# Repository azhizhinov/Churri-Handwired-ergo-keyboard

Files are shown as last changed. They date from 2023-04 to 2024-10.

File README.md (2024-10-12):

This keyboard has been originaly designed by leafflat, this repo is just a fork of his beautiful creation. 

Here is my first custom keyboard design.If you make one, please send me a picture or at me on reddit u/leifflat.

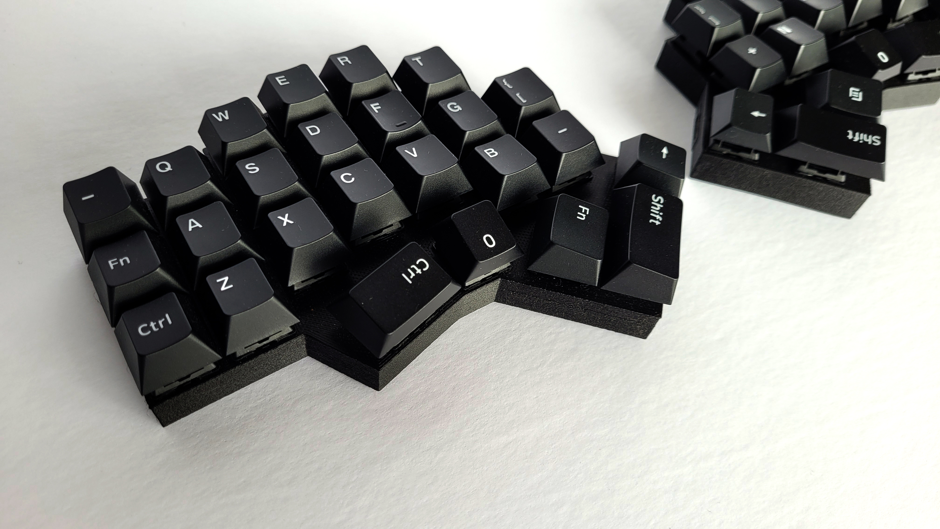
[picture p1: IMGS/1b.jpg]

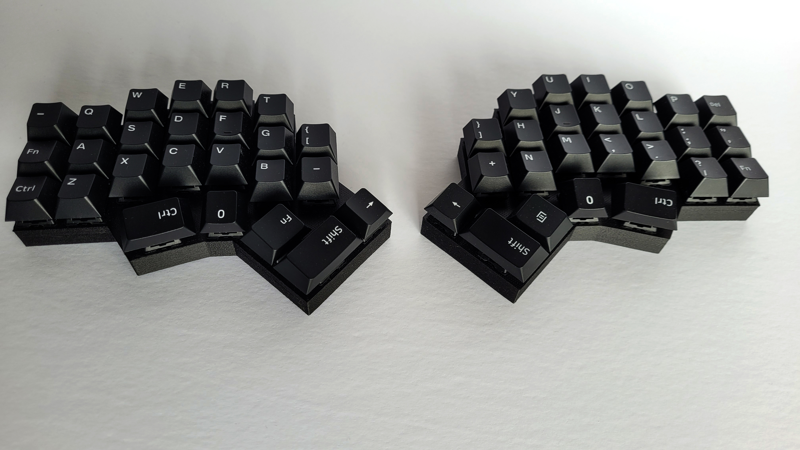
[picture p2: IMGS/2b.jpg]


The keymap is very basic and is for sure missing some things as I intended from the start to use Vial which is the hex I would suggest using, but you can compile it yourself with the provided files.
All the STL files are for one side, and just need to be mirrored for the other side.
<br>
| QTY  | Item |
| --- | --- |
| 6  | 25mm M3 head cap bolts  |
| 18 | 8mm M3 flat head bolts  |
| 12  | M3 heat press inserts (4.5 OD) |
| 12  | M3 nuts  |
| 50 | MX switches  |
| 50 | 1N4148 Diodes  |
| 2 | Pro Micros  |
| 4  | Female USB C breakout boards (see picture below for which one to get specifically)  |
| 2 | Male Micro USB ends  |
| 2  | Tact switches  |

Tenting legs:
Heat press one nut on one side of all 6 through holes to catch the 25mm bolt.<br>
I dipped the tips in Plastidip to give them a better grip on my desk mat, about 12 coats.<br>
<br>
Keyboard:<br>
For the bottom, heat press the bots into the 6 large holes to catch the bolts to connect the tenting body to the keyboard.<br>
Heat press the 12 heat inserts into the body of the keyboard. The breackout boards and Pro Micro can be held down with either doublesided tape or a drop of super glue. You will need to file down 2 of the breakoput boards to fit into place. The tact switch is held in place by super glue. Test the button before glueing as you may need to stretch the hole a bit to make the button easy to press.<br>
<br>
Diagram for wiring:<br>
Diodes should be wired in COL2ROW.<br>
<br>
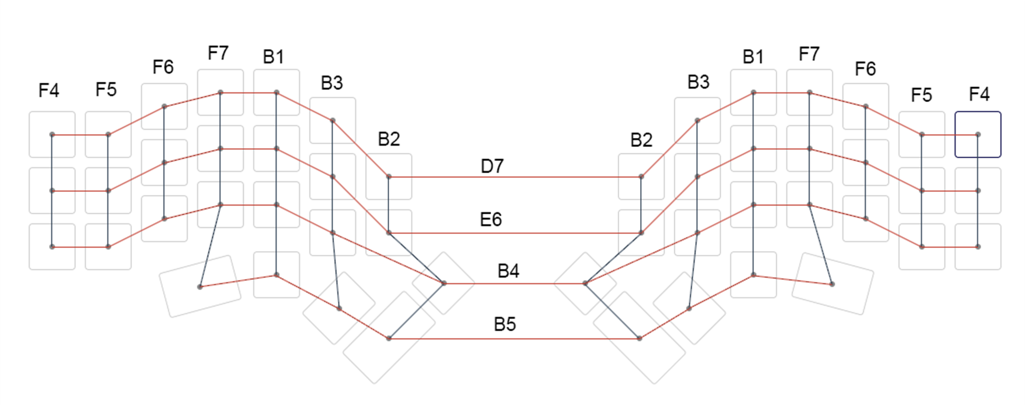
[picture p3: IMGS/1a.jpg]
<br>
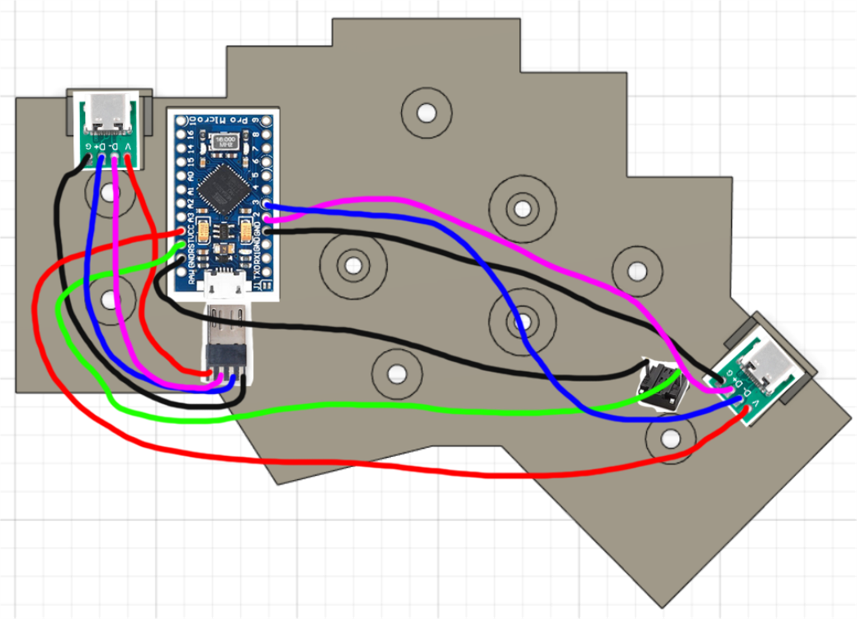
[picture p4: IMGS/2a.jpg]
<br>

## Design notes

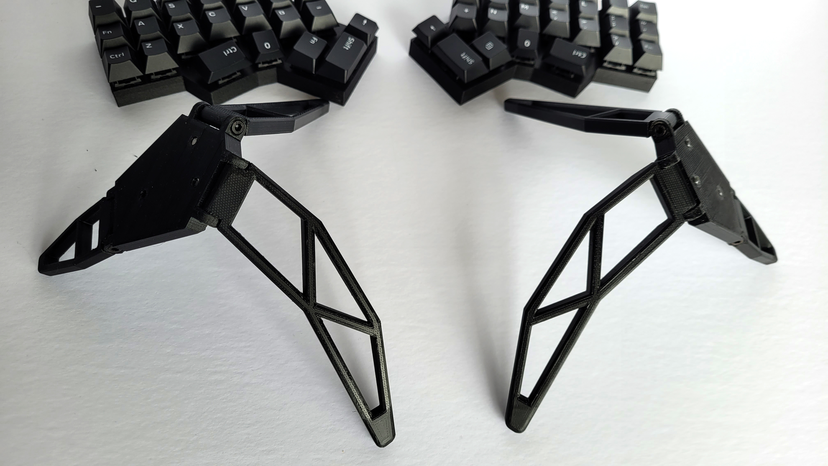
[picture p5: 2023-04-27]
IMGS/5b.jpg

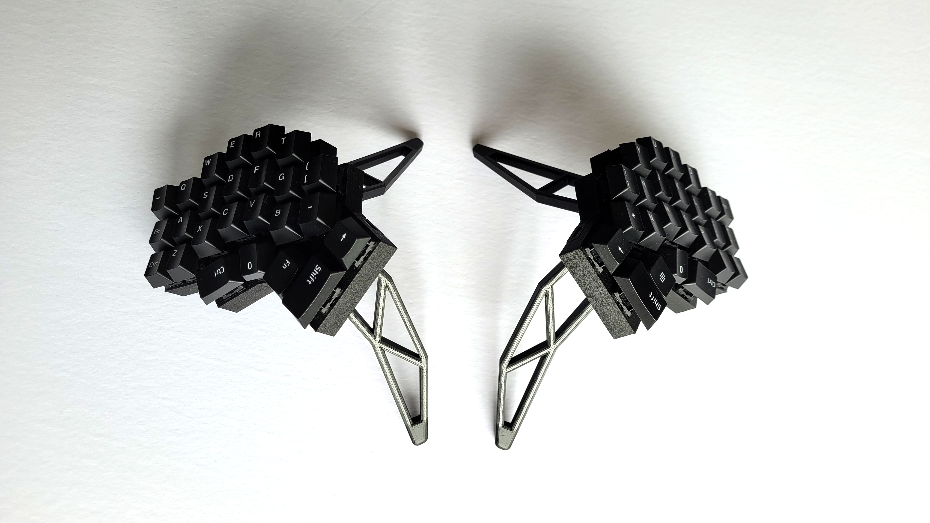
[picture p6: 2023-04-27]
IMGS/4b.jpg

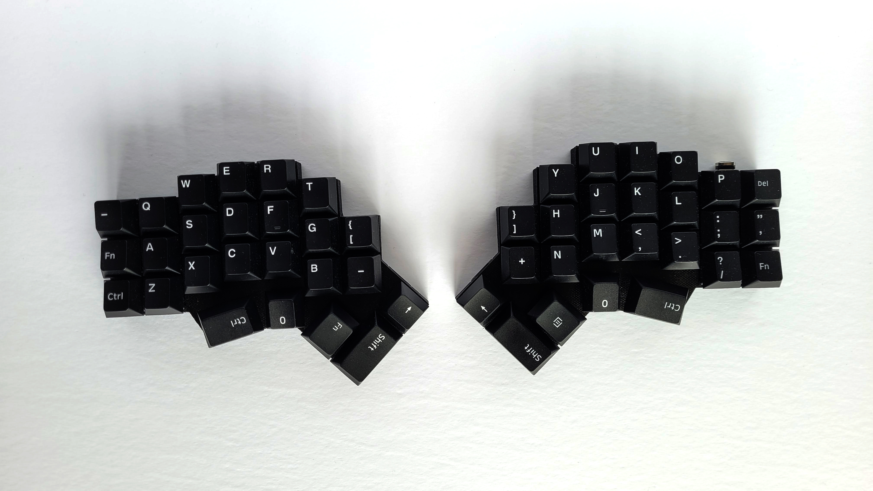
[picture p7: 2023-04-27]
IMGS/3b.jpg

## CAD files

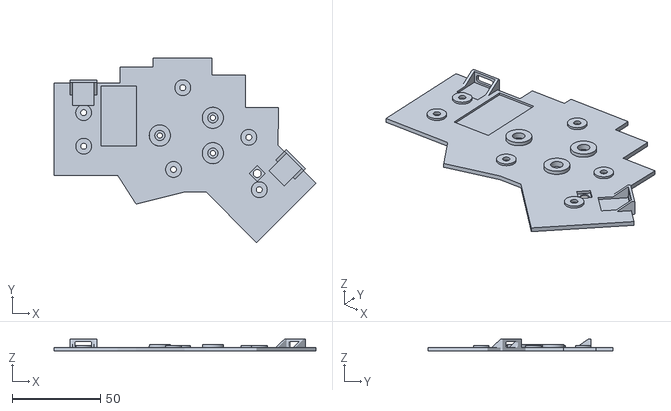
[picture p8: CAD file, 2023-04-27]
STL/Keyboard/Bottom.stl
148.2 x 104.5 x 6.80

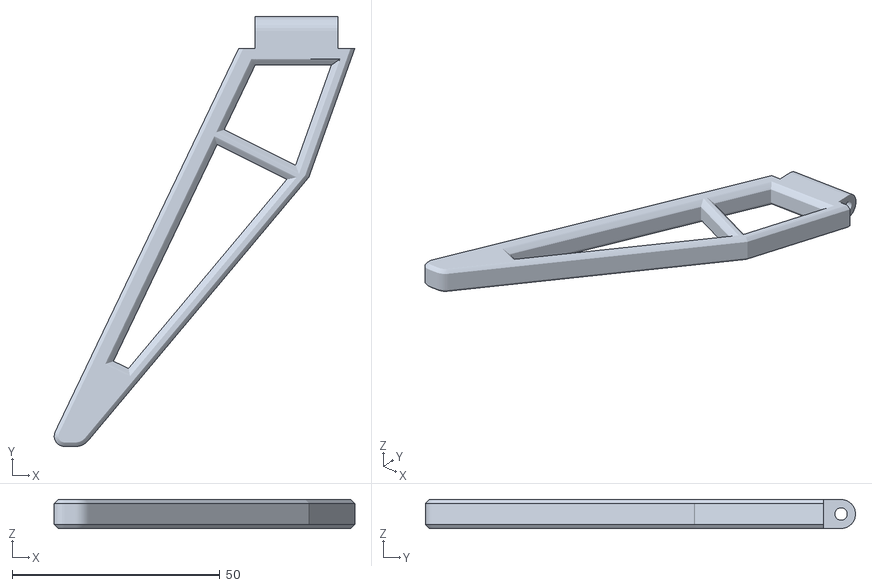
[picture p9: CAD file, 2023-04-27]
STL/Tenting/medium.stl
72.4 x 103.6 x 7.00

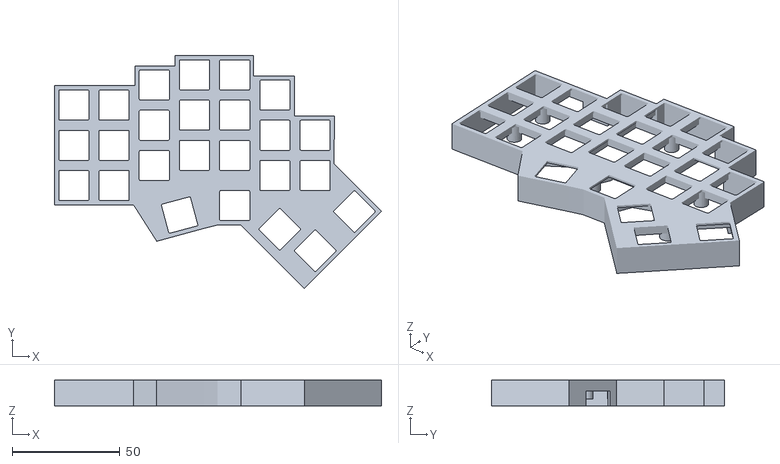
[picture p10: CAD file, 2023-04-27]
STL/Keyboard/Top.stl
152.0 x 108.2 x 12.0

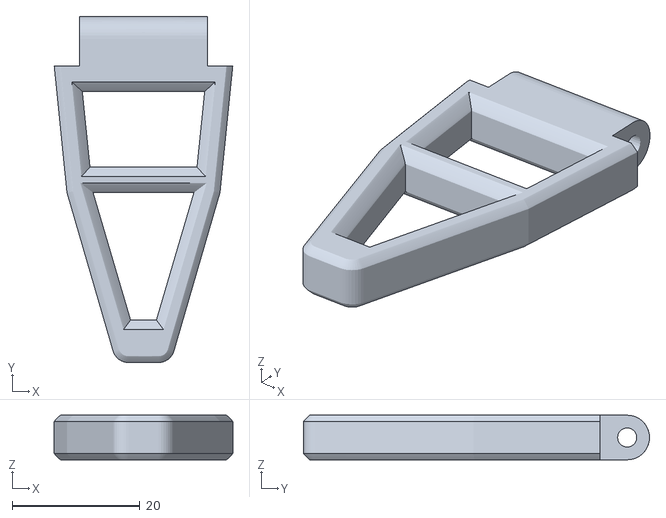
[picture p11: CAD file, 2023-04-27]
STL/Tenting/short.stl
28.0 x 54.2 x 7.00

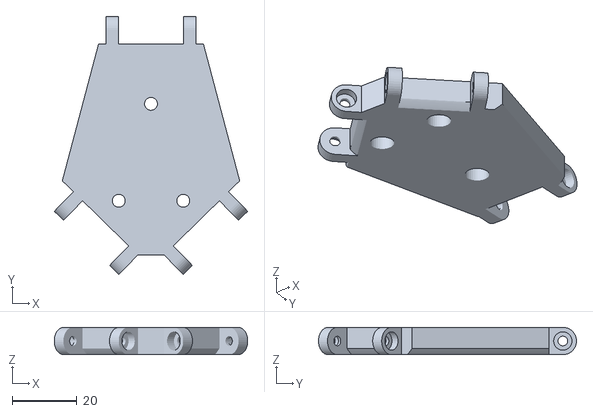
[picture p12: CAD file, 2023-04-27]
STL/Tenting/body.stl
60.0 x 80.0 x 8.50

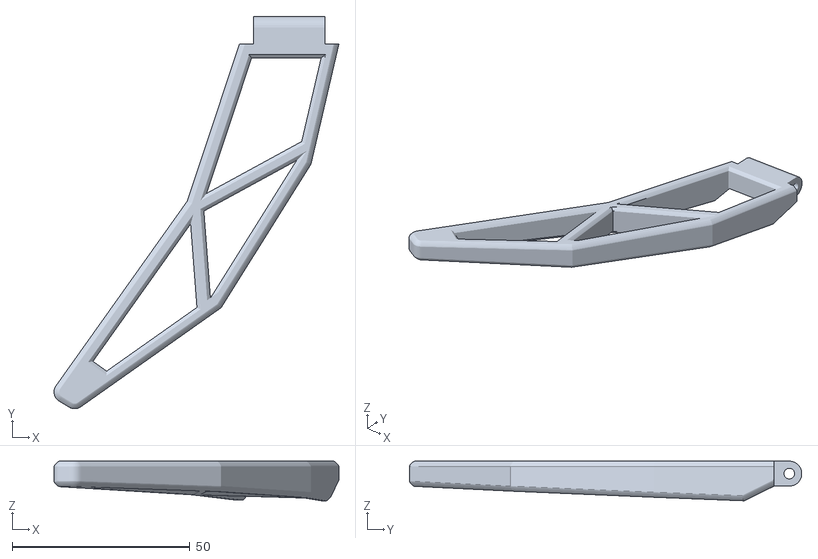
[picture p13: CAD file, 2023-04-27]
STL/Tenting/extra long.stl
80.2 x 110.4 x 11.2

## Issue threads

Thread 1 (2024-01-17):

Churri Ergo Keyboard. PCB version.

azhizhinov, 2024-01-17:
Hello. @leafflat
Saw you are in the process of the Churri PCB creation?
Actually, I've one for you. :-)
[20240117.AZHIZHINOV.CHURRI.00.zip](https://github.com/azhizhinov/Churri-Handwired-ergo-keyboard/files/13962792/20240117.AZHIZHINOV.CHURRI.00.zip)

leafflat, 2024-01-17:
Appreciate it. Ive got an idea for how I want to do this though. Not really a standard way but if I pull it off it should look super stealth.
________________________________
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

azhizhinov, 2024-01-17:
Very interesting. Will wait patiently.
